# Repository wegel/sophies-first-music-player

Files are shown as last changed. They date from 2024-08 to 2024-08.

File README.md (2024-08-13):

# Sophie's First Music Player

This repository contains the design files and source code for Sophie's First Music Player, a custom-built music player designed for children.

## Contents

- [`Sophie's First Music Player.f3d`](Sophie's%20First%20Music%20Player.f3d): Fusion 360 model file
- [`sophies-first-music-player.ino`](sophies-first-music-player.ino): Arduino IDE source code
- [`case.stl`](case.stl): 3D printable file for the case
- [`top.stl`](top.stl): 3D printable file for the top

## Hardware

The music player is built using the following main components:

1. [Adafruit Feather RP2040](https://www.adafruit.com/product/4884): The main microcontroller board.
2. [Adafruit Music Maker FeatherWing w/ Amp](https://www.adafruit.com/product/3436): For audio processing and amplification.
3. [Stereo Enclosed Speaker Set - 3W 4 Ohm](https://www.pishop.ca/product/stereo-enclosed-speaker-set-3w-4-ohm/): speakers
4. Cherry MX Switches and Keycaps: Standard mechanical keyboard switches and keycaps for the buttons.
5. [WeeFancy Mini Portable Charger](https://www.amazon.ca/dp/B0CMTMRDQS): A 10000mAh battery pack for power.
6. [10cm flat male to female usb-c cable](https://www.aliexpress.com/item/1005005371248824.html?spm=a2g0o.order_list.order_list_main.11.76501802kebAYZ)
7. 15x 1N4148 diodes for the keyboard matrix
8. Keep-alive circuit: 1x 1kohm 1/4w resistor, 1x 47ohm 1w resistor, 1x 2N3904 NPN transistor
7. A mini sdcard
8. Small gauge wire (I mainly used a combination of straight and 90° headers with female-female wires)

## Design

### Case Design
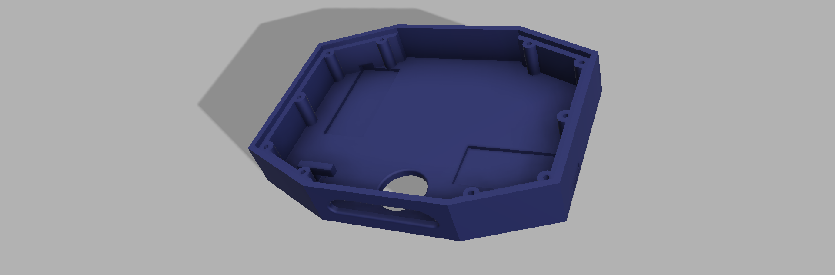
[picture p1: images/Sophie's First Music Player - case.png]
Case Design


### Top Design
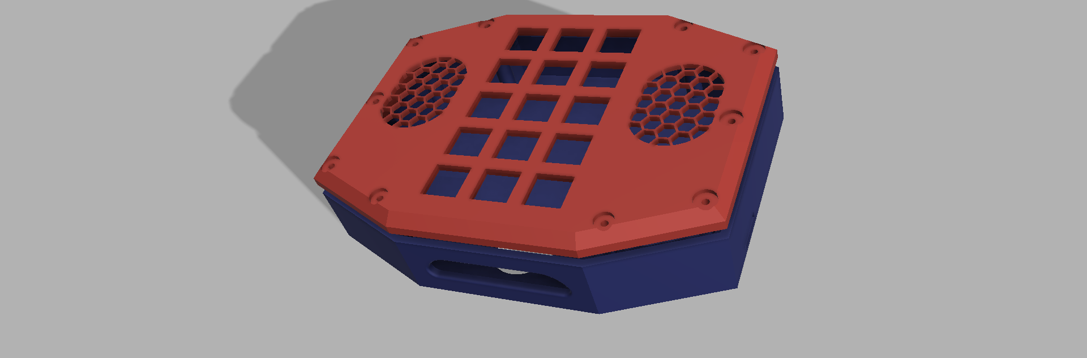
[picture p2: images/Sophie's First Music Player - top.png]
Top Design


### Assembled Device
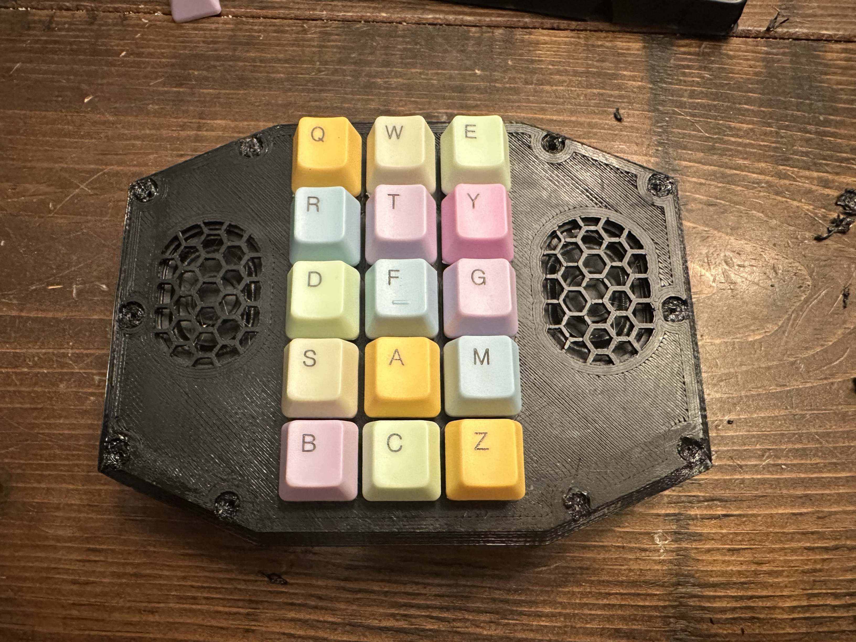
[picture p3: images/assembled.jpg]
Assembled Device


### Internal Components
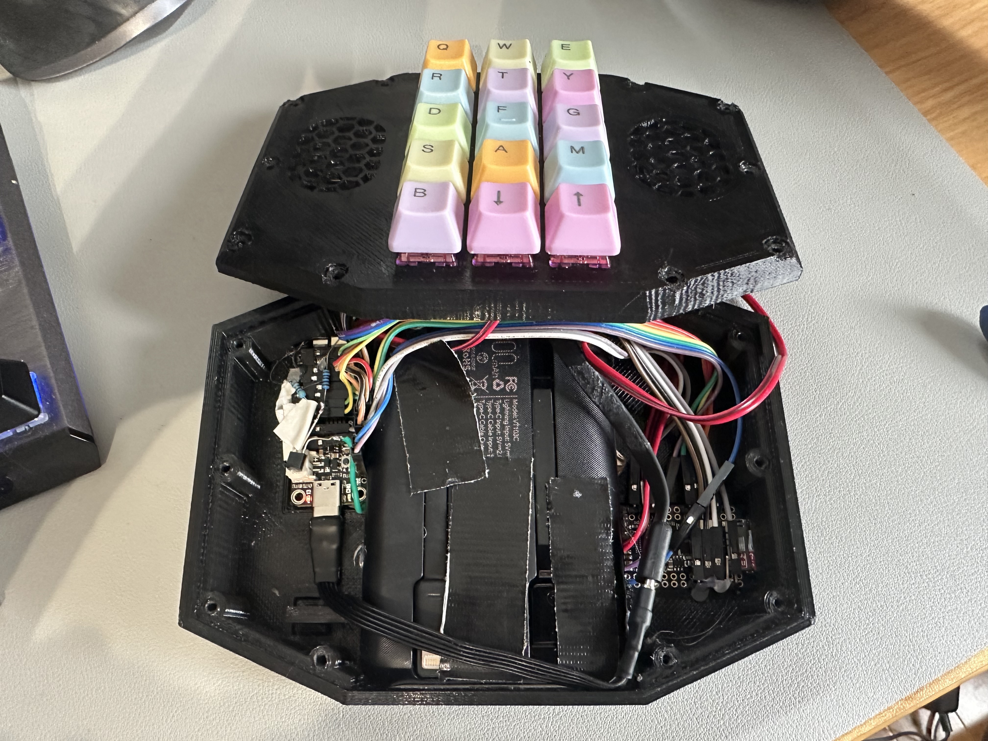
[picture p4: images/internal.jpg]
Internal Components


### Keyboard matrix
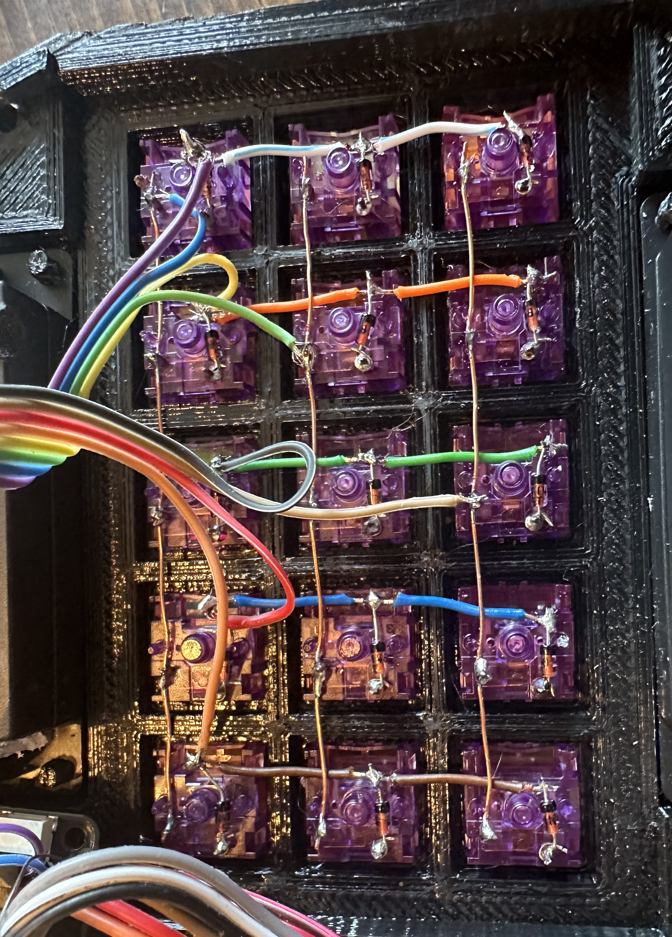
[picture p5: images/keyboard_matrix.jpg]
Keyboard Matric


## Usage

- Each button plays a specific song.
- On the SD card, files have to be named `1 - mysong.mp3`, `2 - another song.mp3`, `15 - lastsong`, etc.
- The first button on the last row acts as a shift key:
  - When shift is held, the next two buttons function as volume down and up, respectively.
- Power on/off is controlled by the push-button on the back of the device.

## Keep-Alive Circuit

To prevent the power bank from automatically shutting off due to low current draw, a keep-alive circuit is implemented:

Keep-Alive Circuit Diagram

This circuit periodically sends a pulse of current to the power bank, simulating device activity. This ensures that the power bank remains on even when the music player is idle for extended periods.

Key features of the keep-alive circuit:
- Uses a GPIO pin to control a transistor
- Sends a brief pulse every 20 seconds
- Consumes minimal power when not active
- Ensures uninterrupted power supply for the music player

The keep-alive functionality is implemented in the Arduino code, allowing for easy adjustment of the pulse frequency and duration if needed.

## License

This project is licensed under the MIT License - see the [LICENSE](LICENSE) file for details.

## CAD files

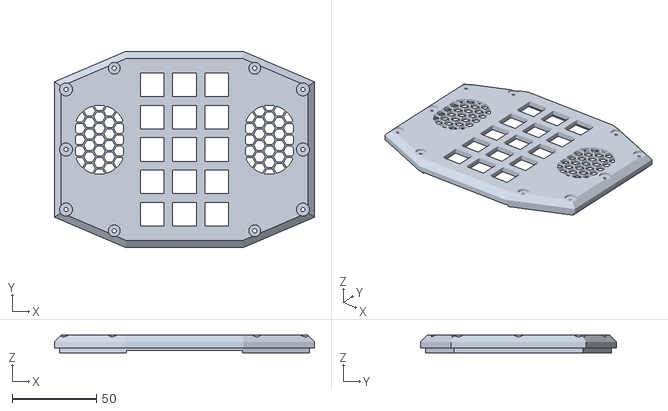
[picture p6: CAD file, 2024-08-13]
top.stl
154.5 x 116.4 x 10.5

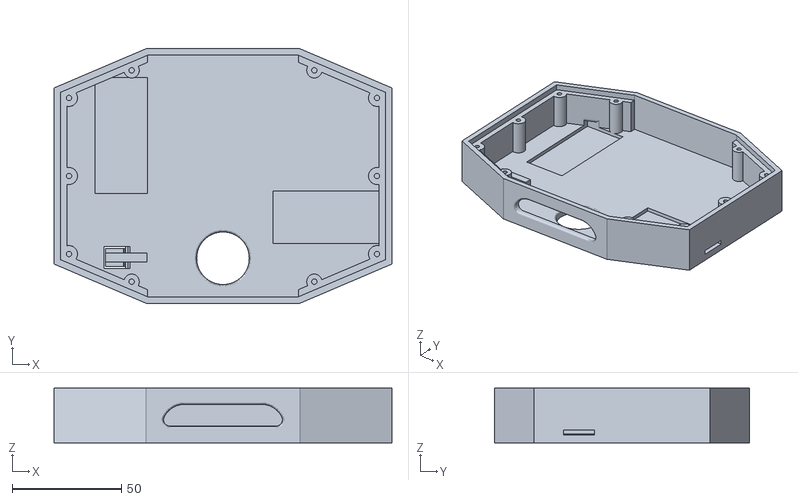
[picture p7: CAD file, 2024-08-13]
case.stl
154.5 x 116.4 x 25.0

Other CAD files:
Sophie's First Music Player.f3d

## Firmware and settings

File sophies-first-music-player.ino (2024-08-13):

#include <SPI.h>
#include <SD.h>
#include <Adafruit_VS1053.h>
#include <Adafruit_NeoPixel.h>
#include <hardware/rtc.h>
#include <pico/stdlib.h>
#include <hardware/clocks.h>
#include <hardware/vreg.h>
#include <hardware/rtc.h>

#define VS1053_RESET   -1
#define VS1053_CS       8
#define VS1053_DCS     10
#define CARDCS          7
#define VS1053_DREQ     9

#define KEEP_ALIVE_PIN 6 // GPIO pin for the keep-alive resistor (GP06, D4)
#define KEEP_ALIVE_ON_TIME 80 // Resistor on time in milliseconds
#define KEEP_ALIVE_INTERVAL 20000 // Time between keep-alive pulses in milliseconds
#define SLOW_MODE_VOLTAGE VREG_VOLTAGE_0_90
#define FAST_MODE_VOLTAGE VREG_VOLTAGE_1_10
#define FAST_MODE_MHZ 133
#define SLOW_MODE_MHZ 18

// Keyboard matrix setup
const int ROW_PINS[] = {26, 24, 28, 12, 2};
const int COL_PINS[] = {3, 11, 29};
const int NUM_ROWS = 5;
const int NUM_COLS = 3;

bool isMusicPlaying = false;
unsigned long lastKeepAliveTime = 0;

bool keyStates[NUM_ROWS][NUM_COLS] = {{false}};
unsigned long lastKeyPressTimes[NUM_ROWS][NUM_COLS] = {{0}};
const unsigned long debounceDelay = 50; // milliseconds

bool shiftKeyPressed = false;
unsigned long shiftKeyPressTime = 0;
const unsigned long shiftKeyHoldTime = 300; // milliseconds to consider as "held down"

uint8_t currentVolume = 40; // Starting volume (0-100, where 0 is loudest and 100 is quietest)

Adafruit_VS1053_FilePlayer musicPlayer =
  Adafruit_VS1053_FilePlayer(VS1053_RESET, VS1053_CS, VS1053_DCS, VS1053_DREQ, CARDCS);

void setup() {
  Serial.begin(115200);
  
  // Initialize keyboard matrix
  for (int i = 0; i < NUM_ROWS; i++) {
    pinMode(ROW_PINS[i], OUTPUT);
    digitalWrite(ROW_PINS[i], HIGH);
  }
  for (int i = 0; i < NUM_COLS; i++) {
    pinMode(COL_PINS[i], INPUT_PULLUP);
  }

  pinMode(LED_BUILTIN, OUTPUT);
  digitalWrite(LED_BUILTIN, LOW);
  
  pinMode(KEEP_ALIVE_PIN, OUTPUT);
  digitalWrite(KEEP_ALIVE_PIN, LOW);

  if (!musicPlayer.begin()) {
    Serial.println(F("Couldn't find VS1053, do you have the right pins defined?"));
    while (1);
  }

  Serial.println(F("VS1053 found"));
  musicPlayer.sineTest(0x44, 500);

  if (!SD.begin(CARDCS)) {
    Serial.println(F("SD failed, or not present"));
    while (1);
  }
  Serial.println("SD OK!");

  musicPlayer.setVolume(currentVolume, currentVolume);
  musicPlayer.useInterrupt(VS1053_FILEPLAYER_PIN_INT);

  Serial.println("Ready to play. Press a key to select a song.");
}

void loop() {
  int key = scanKeyboard();
  handleKeyPress(key);

  if (musicPlayer.stopped() && isMusicPlaying) {
    Serial.println("Song finished playing.");
    isMusicPlaying = false;
    digitalWrite(LED_BUILTIN, LOW);
    slowMode();
  }

  // Keep-alive functionality
  if (!isMusicPlaying) {
    unsigned long currentTime = millis();
    if (currentTime - lastKeepAliveTime >= KEEP_ALIVE_INTERVAL) {
      // Perform keep-alive pulse
      digitalWrite(LED_BUILTIN, HIGH);
      digitalWrite(KEEP_ALIVE_PIN, HIGH);
      delay(KEEP_ALIVE_ON_TIME);
      digitalWrite(KEEP_ALIVE_PIN, LOW);
      digitalWrite(LED_BUILTIN, LOW);
      lastKeepAliveTime = currentTime;
      Serial.println("Keep-alive pulse sent");
    }
  }

  delay(50);
}

int scanKeyboard() {
  for (int row = 0; row < NUM_ROWS; row++) {
    digitalWrite(ROW_PINS[row], LOW);
    for (int col = 0; col < NUM_COLS; col++) {
      bool currentState = digitalRead(COL_PINS[col]) == LOW;
      unsigned long currentTime = millis();
      
      if (currentState != keyStates[row][col]) {
        if (currentTime - lastKeyPressTimes[row][col] > debounceDelay) {
          keyStates[row][col] = currentState;
          lastKeyPressTimes[row][col] = currentTime;
          
          int keyNumber = row * NUM_COLS + col + 1;
          digitalWrite(ROW_PINS[row], HIGH);
          return currentState ? keyNumber : -keyNumber; // Positive for press, negative for release
        }
      }
    }
    digitalWrite(ROW_PINS[row], HIGH);
  }
  return 0; // No change detected
}

void handleKeyPress(int key) {
  if (key == 0) return; // No key event

  bool isKeyPress = key > 0;
  int keyNumber = abs(key);

  // Check if it's the shift key (r5c1)
  if (keyNumber == 13) { // 13 is the key number for r5c1 (5 * 3 - 2)
    handleShiftKey(isKeyPress);
    return;
  }

  // Handle other keys
  if (isKeyPress) {
    if (shiftKeyPressed) {
      // Handle shifted functions
      if (keyNumber == 14) { // r5c2
        decreaseVolume();
        delay(300);
      } else if (keyNumber == 15) { // r5c3
        increaseVolume();
        delay(300);
      }
    } else {
      // Normal key function
      handleNormalKeyPress(keyNumber);
    }
  }
}

void handleShiftKey(bool isPressed) {
  if (isPressed) {
    shiftKeyPressTime = millis();
    shiftKeyPressed = true; // Set to true immediately when pressed
  } else {
    if (millis() - shiftKeyPressTime < shiftKeyHoldTime) {
      // Short press, trigger normal function
      handleNormalKeyPress(13); // 13 is the key number for r5c1
    }
    shiftKeyPressed = false;
  }
}

void handleNormalKeyPress(int keyNumber) {
  if (isMusicPlaying) {
    musicPlayer.stopPlaying();
    isMusicPlaying = false;
    Serial.println("Playback stopped.");
    digitalWrite(LED_BUILTIN, LOW);
    slowMode();
  } else {
    fastMode();
    if (playSong(keyNumber))
      digitalWrite(LED_BUILTIN, HIGH);
  }
}

void increaseVolume() {
  if (currentVolume > 16) {
    currentVolume = currentVolume - 8;
    musicPlayer.setVolume(currentVolume, currentVolume);
    Serial.print("Volume increased to: ");
    Serial.println(currentVolume);
  } else {
    Serial.println("Already at maximum volume");
  }
}

void decreaseVolume() {
  if (currentVolume < 48) {
    currentVolume = currentVolume + 8;
    musicPlayer.setVolume(currentVolume, currentVolume);
    Serial.print("Volume decreased to: ");
    Serial.println(currentVolume);
  } else {
    Serial.println("Already at minimum volume");
  }
}

void slowMode() {
  digitalWrite(LED_BUILTIN, LOW);
  set_sys_clock_khz(SLOW_MODE_MHZ * 1000, true);
  vreg_set_voltage(SLOW_MODE_VOLTAGE);
}

void fastMode() {
  vreg_set_voltage(FAST_MODE_VOLTAGE);
  set_sys_clock_khz(FAST_MODE_MHZ * 1000, true);
}

bool playSong(int songNumber) {
  char prefix[10];
  snprintf(prefix, sizeof(prefix), "%d - ", songNumber);
  
  File root = SD.open("/");
  if (!root) {
    Serial.println("Failed to open root directory");
    return false;
  }

  File file;
  while (file = root.openNextFile()) {
    if (!file.isDirectory()) {
      const char* fileName = file.name();
      
      // Check if the filename starts with a number
      char* endPtr;
      long fileNumber = strtol(fileName, &endPtr, 10);
      
      // If the number matches and is followed by " - "
      if (fileNumber == songNumber && strncmp(endPtr, " - ", 3) == 0) {
        Serial.print("Playing: ");
        Serial.println(fileName);
        musicPlayer.startPlayingFile(fileName);
        isMusicPlaying = true;
        file.close();
        root.close();
        return true;
      }
    }
    file.close();
  }
  
  root.close();
  Serial.println("Song not found");
  return false;
}
